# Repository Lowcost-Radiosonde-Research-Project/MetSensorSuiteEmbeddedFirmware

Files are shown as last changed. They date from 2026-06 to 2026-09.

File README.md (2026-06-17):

# Met Pico Sensor Suite - Firmware Skeleton






Status as of latest revision. Every module now has a real
implementation - BMI330's carries a significant caveat (see below and
its module docstring) since its register map is unverified.

## File layout

| File | Status | Notes |
|---|---|---|
| `config.py` | Real | All pins/addresses/constants in one place. Several `TODO`s remain. |
| `packet.py` | Real | Fixed-width binary record format (`PACKET_FORMAT = "<I15fBBBB"`, 68 bytes). |
| `bme280.py` | Real | Full Bosch compensation formulas, forced-mode reads. I2C bus 1. |
| `rtd_ads1115.py`  | Real | Ratiometric RTD read + Callendar-Van Dusen (T >= 0 C only). I2C bus 1. |
| `ms5611.py` | Real | PROM calibration + 1st/2nd-order temp/pressure compensation. I2C bus 2. |
| `bmi330.py` | **Unverified** | Register map guessed from the related BMI323; may not function as intended - see caveat below. I2C bus 2. |
| `gps_neo_m9n.py`  | Real | NMEA GGA parsing: lat/lon/alt/num_sats/UTC time. |
| `sd_logger.py` | Real | Mounts SD, appends `packet.pack_record()` output, periodic flush. |
| `imet_packet.py`  | Real | Builds the 38-byte iMet-1-RSB GPS+PTU-enhanced downlink frame + CRC-16. |
| `link_uart.py` | Real | Frames and sends one 38-byte iMet frame per cycle to the RF Pico over UART. |
| `main.py` | Real | Two I2C buses, SD log + iMet frame to RF Pico link, per-sensor fault isolation. |

Every sensor module exposes `init_<name>(i2c, addr)` returning an
object with a `read()` method, and `main.py` wraps each init in
`try/except (OSError, ValueError)` and each read in `try/except
OSError` (the only error read() can raise) so one bad/missing sensor
doesn't take down the loop or the log - it just logs NAN for that field
and a `[WARN]` line to the console.

## Bus layout

- **I2C bus 1** (`I2C1*`): ADS1115 (RTD) + BME280
- **I2C bus 2** (`I2C2*`): MS5611 + BMI330
- **UART** (`GPS_UART_*`): NEO-M9N GPS
- **UART** (`LINK_UART_*`): outbound link to the RF Pico, one framed
  38-byte iMet-1-RSB frame per cycle (see `imet_packet.py` /
  `link_uart.py`)
- **SPI** (`SD_*`): SD card

All pin numbers above are placeholders pending the Tuesday wiring
session - see the `TODO`s in `config.py`.

## BMI330 caveat - documentation lacking, driver may not work as intended

`bmi330.py` is written against the BMI323's register map (a related
Bosch part) because verified BMI330-specific register documentation
wasn't available when this was written. The register addresses,
ACC_CONF/GYR_CONF bitfield values, and full-scale range assumptions are
all unverified guesses. **The driver may run without raising any error
and still return meaningless numbers.**

On Tuesday, `init_bmi330()` will print whatever it reads from the
assumed CHIP_ID register (0x00) as a diagnostic - note that value down.
If accel/gyro readings look like noise, sit constant, or are far
outside physical range (accelerometer magnitude should be close to 1g
at rest), the register map guess is wrong and `bmi330.py` needs
revisiting against real BMI330 documentation (Bosch's BMI3 Sensor API
repo is the best starting point once it covers BMI330). This isn't
blocking for Wednesday - BMI330 isn't part of that test.

## Field naming convention

`packet.FIELD_NAMES` prefixes every field with the sensor that owns it
(`bme280_*`, `ms5611_*`, `rtd_*`, `bmi330_*`, `gps_*`). BMI330 fields
are in milli-g / milli-deg/s (`_mg` / `_mdps`) rather than g / deg-per-s
- worth keeping in mind when the real BMI330 driver is written, since
the conversion from raw counts will need to land in those units.

The GPS record has `gps_num_sats` plus `gps_hour`/`gps_minute`/
`gps_second` (UTC time of fix), but no fix-type field - `gps.read()`
returns a 7-tuple `(lat, lon, alt, num_sats, hour, minute, second)`.
Position/altitude are NAN and the satellite/time fields are
`NO_DATA_U8` until a checksum-valid GGA sentence with a non-zero fix
quality has been parsed. If you want fix-quality (e.g. for
SondeHub-style reporting) added too, that's a small change to
`packet.py` (one more `B` field) and `gps_neo_m9n.py`'s `_parse_gga()`.

## iMet-1-RSB downlink frame

Each cycle, after the SD record is written, `main.py` builds a
separate 38-byte frame via `imet_packet.pack_frame()` - a GPS Data
Packet (`PKT_ID=0x02`, 18 bytes) immediately followed by a PTU
(enhanced) Data Packet (`PKT_ID=0x04`, 20 bytes), each with its own
CRC-16, matching InterMet's "Appendix A - Binary Radiosonde Packet
Definition" as decoded by `imet1rsb`. This frame - not the `packet.py`
record - is what gets sent over `link_uart` to the RF Pico for AFSK
modulation; `packet.py` stays SD-only.

Current sensor -> iMet field mapping (set in `main.py`, easy to
change - it's just which `record[...]` value is passed to which
`imet_packet` keyword argument):

| iMet field | Source | Notes |
|---|---|---|
| GPS lat/lon/alt/num_sats/hour/min/sec | `gps_*` record fields | real NMEA GGA parsing; NAN/NO_DATA until a fix is acquired |
| P (pressure) | `ms5611_pressure_hpa` | **TODO**: confirm vs. BME280 as the primary pressure source |
| T (primary temp) | `bme280_temp_c` | |
| U (humidity) | `bme280_humidity_pct` | |
| Vbat | hardcoded NAN | **TODO**: no battery-voltage sensing exists yet (new ADC channel) |
| Tint (internal temp) | `bme280_temp_c` | **TODO**: currently duplicates T - confirm intent |
| Tpr (probe temp) | `rtd_temp_c` | |
| Tu (aux temp) | hardcoded NAN | **TODO**: no mapping defined - InterMet's intended use of this field is unclear |

All of the NAN/sentinel placeholders above pack safely (verified in
`imet_packet.py`'s `_scaled_*`/`_encode_altitude` helpers - they map
NAN to the field's "no data" value rather than raising), so the frame
is well-formed even with everything still stubbed.

## Before Tuesday (no hardware needed)

- [ ] Get a copy of `sdcard.py` onto the board. Easiest path in
      Thonny/REPL: `import mip; mip.install("sdcard")`. This is the
      standard MicroPython SD-over-SPI block driver - `sd_logger.py`
      imports it as `sdcard`.
- [ ] Skim `config.py` for the `TODO` items - nothing blocks you from
      reading the code now, but these are the values you'll set Tuesday.

## Tuesday, once hardware is in hand

- [ ] Update `config.py` pin numbers for both I2C buses, SPI (SD), GPS
      UART, the RF Pico link UART, and `REGULATOR_EN_PIN` (LM2596 3.3V
      rail enable) to match actual wiring.
- [ ] Confirm `RTD_MUX` / `REF_MUX` (which ADS1115 differential pair is
      the RTD vs. the reference resistor) and `ADS1115_GAIN` (PGA
      setting), based on the RTD interface board.
- [ ] Confirm `MS5611_I2C_ADDR` and `BMI330_I2C_ADDR` once those boards
      are wired. MS5611 and GPS now have real drivers, so a wrong
      address will surface as `[WARN] ... init failed` from
      `_safe_init` rather than silently logging NaN.
- [ ] For BMI330: note the `[INFO] BMI330 CHIP_ID register read as
      0x..` line at startup and sanity-check accel/gyro readings
      against the caveat above - this driver's register map is a
      guess.
- [ ] Run `main.py`. With only BME280 + RTD wired, expect `[WARN]`
      lines at startup for MS5611/BMI330/GPS init or SD mount (if not
      present) - that's expected, the loop should keep running and
      print live T/P/RH/RTD values once per second.

## Wednesday (storm chase)

The console line each cycle:

```
t=   12345ms  T= 23.45C  P=1006.32hPa  RH= 45.2%  RTD= 23.10C
```

gives a live sanity check that BME280 and RTD agree roughly with each
other and with ambient conditions. The SD card (if mounted) accumulates
`PACKET_SIZE`-byte (68-byte) binary records in `/sd/metlog.bin` - decode
with `packet.unpack_record()` in a small post-processing script, reading
`PACKET_SIZE` bytes at a time.

## Known gaps / next steps

- RTD conversion only handles T >= 0 C (Callendar-Van Dusen quadratic
  inversion). The sub-zero cubic-term inversion needs to be added before
  the actual flight.
- BMI330 is unverified - see the dedicated caveat section above and
  `bmi330.py`'s module docstring before trusting any IMU data.
- `link_uart.py` now sends a 38-byte iMet frame instead of the
  65-byte `packet.py` record - see "iMet-1-RSB downlink frame" above
  for the sensor mapping and its open TODOs (Vbat sensing, GPS UTC
  time, P/Tint/Tu assignment).
- `imet_packet.py` matches the field layout and CRC algorithm from
  `imet1rsb.c`'s source, but hasn't been cross-checked byte-for-byte
  against a compiled run of that decoder yet. Worth doing once there's
  a spare moment - compile `imet1rsb.c`, feed it a known frame, and
  confirm its `crc16()` agrees with `imet_packet.crc16()`.
- The RF Pico's receive-side parser for `link_uart`'s frame format
  (sync bytes + length + checksum) doesn't exist yet - that's firmware
  for the other board, out of scope here, but the frame format is
  documented at the top of `link_uart.py` so it can be matched.
- `main.py` currently runs everything on a single core via a simple
  fixed-interval loop. If SD writes, link UART sends, or sensor reads
  start causing timing jitter once everything is real, revisit
  splitting acquisition and logging across the two cores with
  `_thread`.

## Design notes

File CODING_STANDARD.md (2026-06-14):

# Lowcost Radiosonde Research Project - Coding Standard

**Revision:** 1.0
**Applies to:** All firmware (C/Pico SDK , MicroPython) and ground-station tooling.

## Table of Contents

1. [General Principles](#1-general-principles)
2. [Repository Structure](#2-repository-structure)
3. [C - Pico SDK Firmware](#3-c--pico-sdk-firmware)
    - 3.1 [Naming Conventions](#31-naming-conventions)
    - 3.2 [Formatting & Braces](#32-formatting-braces)
    - 3.3 [Comments & Documentation](#33-comments--documentation)
    - 3.4 [Header Files](#34-header-files)
    - 3.5 [Error Handling](#35-error-handling)
    - 3.6 [Types & Fixed Width Integers](#36-types--fixed-width-integers)
    - 3.7 [Memory & Pointer](#37-memory--pointers)
    - 3.8 [Interrupt & DMA Safety](#38-interrupt--dma-safety)
4. [MicroPython](#4-micropython)
    - 4.1 [Naming Conventions](#41-naming-conventions)
    - 4.2 [Formatting](#42-formatting)
    - 4.3 [Comments & Docstrings](#43-comments--docustrings)
    - 4.4 [Error Handling](#44-error-handling)
5. [Version Control Practices](#5-version-control-practices)
6. [Build System](#6-build-system)

---

## 1. General Principles
- **Clarity over cleverness** You are not the only one reading your code. Please favor explicit, readable constructs even when a terse alternative exists.

- **One concern per module** Each file `.c`/`.h` or `.py` file should address a single problem. It should contain a single logical subsystem e.g. : GPS parsing, sensor acquisition, telemetry framing, etc..
- **Fail loudly in development not in flight** Use assertions and diagnostic output debug builds; ensure flight builds degrade safely without halting.
- **Document the *why* and not the *what*** The code itself shows what is happening; comments should explain non-obvious design decisions and hardware-specific constraints.

---

## 2. Repository Structure

coming soon / not needed for this file

---

## 3. C - Pico SDK Firmware

### 3.1 Naming Conventions
| Construct | Convention | Example |
|---|---|---|
|Functions| `module_verb_noun()` snake_case |`gps_parse_frame()` |
|Variables (local) | snake_case | `byte_count`|
|Variables (global) | `g_` prefix + snake_case | `g_fix_valid` |
|Constraints / `#define` | SCREAMING_SNAKE_CASE | `MAX_PACKET_LENGTH` |
| Macros | SCREAMING_SNAKE_CASE | `SWAP_BYTES(x)` |
| Typedefs (structs) | PascalCase + `_t` suffix | `GpsFrame_t` |
| Enums | PascalCase + `_t` suffix , members prefixed | `TxState_t`, `TX_IDLE` |
| File names | snake_case | `telemetry_encoder.c` |

### 3.2 Formatting & Braces

**Allman style is mandatory** for all control flow constructs. Opening braces should go on their own line.

```c
/* Correct - Allman style */
if (fix_valid)
{
    gps_parse_frame(&frame);
}
else
{
    log_warn("No GPS fix");
}

/* Incorrect */
if (fix_valid){
    gps_parse_frame(&frame);
}
```
Additional rules:

- **Indent with 4 spaces**
- **Line length:** Keep lines at or under 100 chars
- **One statement per line** Never write `if(x) do_thing();` on a single line.
- **Always brace single-statement bodies.** Omitting braces for one-liner `if`/`for` bodies is not permitted.
- **Blank lines:** Use a single blank line to separate logical sections within a function; two blank lines between top-level definitions in a file.
- **Pointer declarations:** Right attach '*' ie attach to the variable name, not type.

```c
uint8_t *buf;  /*correct*/
uint8_t* buf; /*incorrect */
```
### 3.3 Comments & Documentation

Use Doxygen-style block comments on all public functions and type definitions in headers:

```c
/**
 * @brief Parse a raw NMEA sentence into a GpsFrame_t.
 *
 * @param sentence Null-terminated NMEA string (e.g. "$GPGGA,....").
 * @param out      Pointer to a caller-allocated GpsFrame_t to populate.
 * @return true on successful parse, false if the sentence is malformed or the checksum fails
 */
 bool gps_parse_sentence(const char *sentence, GpsFrame_t *out);
```
Inline comments use '/* */' and are placed **above** the line they describe, not at the end of the line, unless the comment is very short:
```c
/* Correct */
/* Shift left by 4 to align the SI4063 register format. */
reg_val = raw_freq << 4;
/* Acceptable for short notes. */
uint32_t timeout_ms = 500; /* POR stabilisation time per datasheet */
```
Do not leave commented-out code in committed files. Use version control to recover old implementations.

### 3.4 Header Files

- Use `#pragma once` at the top of every header.
- Headers expose **Only what the consumers need**. Keep internal helpers in the `.c` file or in a separate `_internal.h` that is not installed.
- Always include all headers that your header directly depends on - do not rely on transitive inclusion.
- Group includes in the following order, separated by a blank line:
    1. Standard C headers (`<stdint.h>`, `<stdbool.h>`, etc.)
    2. Pico SDK headers (`"pico/stdlib.h"`, `"hardware/uart.h"`, etc.)
    3. Project headers (`"gps.h"`, `"telemetry.h"`, etc.)

```c
#pragma once

#include <stdint.h>
#include <stdbool.h>

#include "pico/stdlib.h"
#include "hardware/spi.h"

#include "telemetry.h"
```

### 3.5 Error Handling

- Functions that can fail **must** return a status. Prefer `bool` for simple pass/fail, or a project-defined `SondeStatus_t` enum for multi-error subsystem.
-Never silently discard a return value from a function that can fail. If the result is intentionally unused, cast to `(void)`;
- In debug builds, use `assert()` to catch programming errors. In flight builds, assert should compile out (`NDEBUG`).
- Do not use `while(1)` panic loops in flight code - always attempt graceful recovery or safe-state entry.

### 3.6 Types & Fixed-Width Integers

- Prefer fixed-width types from `<stdint.h>` for all hardware-interfacing protocol code: `uint8_t`, `uint16_t`, `uint32_t`, etc..
- Use `size_t` for buffer lengths and loop indices over arrays.
- Use `bool` (from `<stdbool.h>`) for boolean states. Never use `int` as a boolean.
- Avoid `float` in ISR context. Use fixed-point (`int32_t` with a documented scale factor) or defer float math to the main loop.

### 3.7 Memory & Pointers

- No dynamic memory allocation (`malloc`/`free`) in flight firmware. All buffers are statically allocated.
- Clearly document buffer ownership: who allocates, who frees (if ever), and who may write.
- Mark pointers to read-only data as `const`.
- Mark output-only pointer parameters clearly in the Doxygen `@param` docs.

### 3.8 Interrupt & DMA Safety

- Variables shared between ISR and main-loop context **must** be declared `volatile`.
- Accesses to multi-byte shared variables must be protected (disable IRQ + restore, or use the Pico SDK's `__dmb()` / critical section APIs).
- Keep ISR bodies minimal - set a flag or write a ring buffer; do all heavy processing in the main loop.
- DMA buffer pointers must be 4-byte aligned. Use `__attribute__((aligned(4)))`.

---

## 4. MicroPython

### 4.1 Naming Conventions

| Construct | Convention | Example |
|---|---|---|
| Functions | snake_case | `decode_frame` |
|Variables | snake_case | `packet_count`|
|Constants | SCREAMING_SNAKE_CASE | `BAUD_RATE` |
| Classes | PascalCase | `SondeDecoder` |
| Private members | leading underscore | `_checksum_` |
| Modules/files | snake_case | `telemetry_decoder.py` |

### 4.2 Formatting

- Follow **PEP 8** as the baseline style guide.
- **Indent with 4 spaces**
- **Line length:** 100 character maximum (to stay consistent with the C standard above).
- Two blank lines between top-level function and class definitions; one blank line between methods within a class.
- Imports are grouped in PEP 8 order (stdlib -> third-party -> local), each grouped separated by a blank line.

```python
import struct
import sys

import serial

from sonde.telemetry import SondeDecoder
```

### 4.3 Comments and Docstrings

All public functions, classes, and methods get a docstring. Use Google-style docstrings:

```python
def decode_frame(raw: bytes) -> dict:
    """Decode a raw telemetry frame into a dictionary of sensor values.

    Args:
        raw: Raw byte payload from the radio receiver, including the
             2-byte sync word and trailing CRC.
    
    Returns:
        A dict with keys 'lat', 'lon', 'alt_m', 'temp_c', 'rh_pct',
        'pressure_hpa'. Missing or invalid fields are None.

    Raises:
        ValueError: If the sync word is absent or the CRC fails.
    """
```

Inline comment us `#` with a single space, placed above the relevant line:

```python
# Convert raw ADC count to temperature using datasheet equation
temp_c = (raw_adc * 0.0625) - 40.0
```

### 4.4 Error Handling

- Use specific exception types, never bare `except:`.
- Log errors with enough context to reconstruct what went wrong (packet binary dump, timestamp, etc.).
- Ground-station tools should never crash silently -  at a minimum, print a human readable error and continue or exit cleanly

```python
try:
    frame = decode_frame(raw_bytes)
except ValueError as e:
    print(f"[WARN] Bad frame at t = {timestamp}: {e} | raw = {raw_bytes.binary()}")
    continue
```

---

## 5. Version Control Practice (Git)

- **Branch naming:** `feature/<short-description>`, `fix/<short-description>`, `chore/<short-description>`.
- **Commit messages** Use the imperative mood and keep the subject line under 72 characters.
    - Good: `Added GPS checksum validation to parser`
    - Bad: `fixed stuff` / `WIP`
- Every commit on `main` must build cleanly with zero warning s at the project's standard warning level (`-Wall -Wextra` for C).
- Do not commit generated build artifacts, `.uf2` binaries, or IDE-specific files. Use `.gitignore`.

---

## 6. Build Systems

- The firmware uses **CMake** via the Pico SDK's standard project structure.
- Enable warnings-as-errors in CI: ass `--Werror` to `CMAKE_C_FLAGS` in the CI build configuration (not in the development default, to avoid friction during active development).
- The recommended compiler flag set for development builds:

```cmake
target_compile_options(sonde_firmware PRIVATE
    -Wall
    -Wextra
    -Wshadow
    -Wdouble-promotion
    -Wformat=2
    -fno-common
)
```

- Python tooling dependencies are pinned in `tools/requirements.txt` with exact versions.

---
*This document is a living standard. Propose changes via pull request with a brief rational in the PR description.*

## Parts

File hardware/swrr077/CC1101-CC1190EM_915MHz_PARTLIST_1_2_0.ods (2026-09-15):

CC1101-CC1190EM 915 MHz 1.2.0
Ref. | Part name | Pcs/unit | Description | Manufacturer | Part number | Supplier | Ordering code | Alt. Manufacturer | Alt. Part number | Alt. Supplier | Alt. Ordering code | Comments
U1 | CC1101 | 1 | Single-chip transceiver | TI | CC1101 | TI | U1 | CC1101 | 1 | Single-chip transceiver | TI | CC1101 | TI | CC1101
U2 | CC1190 | 1 | LNA and PA 26 dBm | TI | CC1190 | TI | CC1190
C28 | C_0402 | 1 | Capacitor, general, 0402; Do not mount
C125 | C_0P8_0402_NP0_B_50 | 1 | Capacitor, 0.8p, 0402, NP0, +/-0.1pF, 50V | Murata | GRM1555C1HR80BZ01D
C41;C51;C91;C111;C141;C151;C181 | C_100N_0402_X5R_K_10 | 7 | Capacitor, 100n, 0402, X5R, 10%, 10V | Murata | GRM155R71A104KA01D
C124 | C_100P_0402_NP0_J_50 | 1 | Capacitor, 100p, 0402, NP0, 5% 50V | Murata | GRM1555C1H101JZ01D
C2 | C_10U_0603_X5R_M_4 | 1 | Capacitor, 10u, 0603, X5R, 20%, 4V | Murata | GRM188R60G106ME47D
C22;C52;C81 | C_12P_0402_NP0_J_50 | 3 | Capacitor, 12p, 0402, NP0, 5%, 50V | Murata | GRM1555C1H120JZ01D
C101;C132 | C_15P_0402_NP0_J_50 | 2 | Capacitor, 15p, 0402, NP0, 5%, 50V | Murata | GRM1555C1H150JZ01D
C27 | C_1N_0402_NP0_J_50 | 1 | Capacitor, 1n, 0402, NP0, 5%, 50V | Murata | GRM1555C1H102JA01D
C121 | C_1P0_0402_NP0_C_50 | 1 | Capacitor, 1p, 0402, NP0, +/-0.25pF 50V | Murata | GRM1555C1H1R0CZ01D
C122;C131 | C_1P5_0402_NP0_C_50 | 2 | Capacitor, 1p5, 0402, NP0, +-0.25pF, 50V | Murata | GRM1555C1H1R5CZ01D
C1;C30 | C_1U_0402_X5R_K_6P3 | 2 | Capacitor, 1u, 0402, X5R, 10%, 6.3V | Murata | GRM155R60J105KE19D
C3 | C_220P_0402_NP0_J_50 | 1 | Capacitor, 220p, 0402, NP0, 5%, 50V | Murata | GRM1555C1H221JA01D
C161 | C_27P_0402_NP0_J_50 | 1 | Capacitor, 27p, 0402, NP0, 5%, 50V | Murata | GRM1555C1H270JZ01D
C24 | C_3P3_0402_NP0_C_50 | 1 | Capacitor, 3p3, 0402, NP0, +-0.25pF, 50V | Murata | GRM1555C1H3R3CZ01D
C21;C26;C123 | C_47P_0402_NP0_J_50 | 3 | Capacitor, 47p, 0402, NP0, 5%, 50V | Murata | GRM1555C1H470JZ01D
C25 | C_7P5_0402_NP0_C_50 | 1 | Capacitor, 7p5, 0402, NP0, +/-0.25pF 50V | Murata | GRM1555C1H7R5CZ01D
U3 | EPCOS_B3588 | 1 | SAW filter, 915 MHz | EPCOS | B3588 | Arrow | B39921B3588U410
L25 | L_10N_0402_G_LQW | 1 | Inductor, 10n, 0402, ±2%, wire-wound type | Murata | LQW15AN10NG00D | Mouser | 81-LQW15AN10NG00D
L2 | L_11N_0402_J_LQW | 1 | Inductor, 11n, 0402, ±5%, wire-wound type | Murata | LQW15AN11NJ00
L121;L131 | L_12N_0402_J_LQW | 2 | Inductor, 12n, 0402, ±5%, wire-wound type | Murata | LQW15AN12NJ00D
L122;L132 | L_18N_0402_J_LQW | 2 | Inductor, 18n, 0402, ±5%, wire-wound type | Murata | LQW15AN18NJ00D
L130 | L_1N5_0402_S | 1 | Inductor, 1n5, 0402, Monolithic type, +/-0.3 nH | Murata | LQG15HS1N5S02D |  |  | Coilcraft
L21 | L_22N_0603_J_LQW | 1 | Inductor, 22n, 0603, ±5%, wire-wound type | Murata | LQW18AN22NJ10
L23 | L_2N9_0402_B_LQW | 1 | Inductor, 2n9, 0402, wire-wound type, ±0.1nH | Murata | LQW15AN2N9B00D
L22 | L_7N5_0402_G_LQW | 1 | Inductor, 7n5, 0402, ±2%, wire-wound type | Murata | LQW15AN7N5G00 | ACTE
L24 | L_9N1_0402_G_LQW | 1 | Inductor, 9n1, 0402, ±2%, wire-wound type | Murata | LQW15AN9N1G00D
L1 | L_BEAD_102_0402 | 1 | EMI filter bead, 0402 1k ohms Tape GHz Band Gen Use | Murata | BLM15HG102SN1D | ACTE
P4 | PINROW_SMD_2X7_2.54MM_PEG | 1 | 2x7 pinrow, 2.54mm pitch, SMD type with locating peg | GradConn | BB02-HP141-KB3-060A00 | Freber
R3-5 | R_10K_0402_F | 3 | Resistor, 10k ohms, 0402, ±1% | Koa | RK73H1ETTP1002F | ELFA | 60-485-32
R161 | R_10_0402_G | 1 | Resistor, 10 ohms, 0402, 2% | Koa | RK73H1ETTP10R0F (±1%) | ELFA | 60-470-96
R141 | R_3K3_0402_F | 1 | Resistor, 3k3 ohms, 0402, ±1% | Koa | RK73H1ETTP3301F | ELFA | 60-482-92
R151 | R_47_0402_G | 1 | Resistor, 47 ohms, 0402, 2% | Koa | RK73H1ETTP47R0F (±1%) | ELFA | 60-474-19
R171 | R_56K_0402_F | 1 | Resistor, 56k ohms, 0402, ±1% | Koa | RK73H1ETTP5602F | ELFA | 60-488-96
P3 | SMA_SMD | 1 | SMA connector, straight SMD-mount | Hus-Tsan Group Taiwan | SMA-10V21-TGG | EC Partner A/S | SMA-10V21-TGG
P1-2 | SMD_SOCKET_2x10 | 2 | SMD pinrow socket, .050 spacing, 2x10 | Samtec | SFM-110-02-SM-D-A-K-TR | Abacus |  |  |  | AFU, Arrow |  | Yes
P5 | Shield BMIS-202 | 1 | Surface Mount Shield Two-Piece. Cover ordered separately | Laird | BMI-S-202-F | ELFA | 50-011-28
P5 cover | Shield BMIS-202 cover | 1 | Cover for SHIELD BMIS-202 | Laird | BMI-S-202-C | ELFA | 50-011-36
X1 | X_26.000/20/40/40/10 | 1 | Crystal, 26.000000MHz, 10.0pF, 50 ohms max, 20/40 ppm, -40C to +85C | NDK | NX3225GA, EXS00A-CG01972 | NDK | NX3225GA, EXS00A-CG01972
Total number of components |  | 58

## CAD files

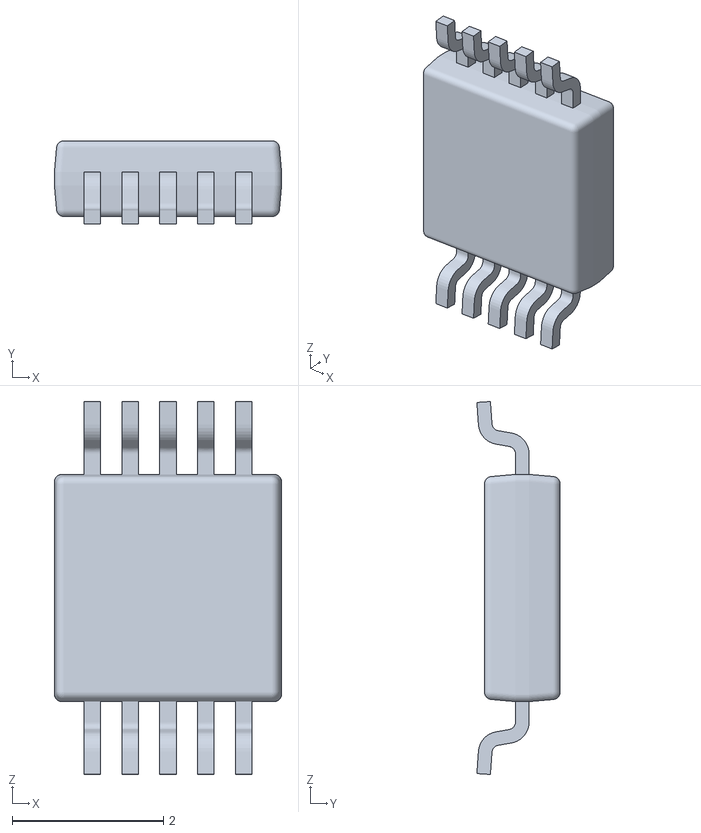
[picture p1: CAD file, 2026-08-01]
hardware/Parts/ADS1115LIDGSR/DGS0010A.stl
3.00 x 1.10 x 4.93

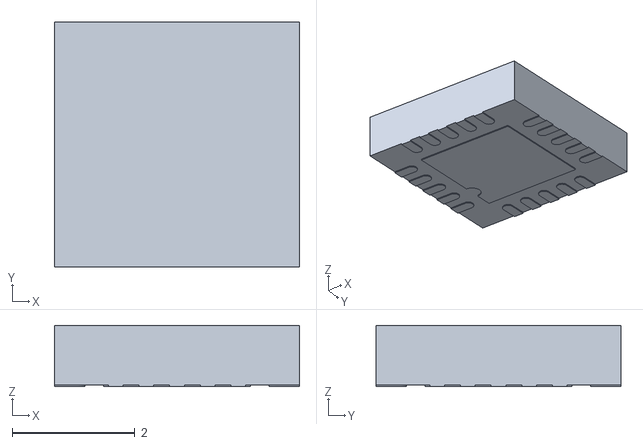
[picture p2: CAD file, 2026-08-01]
hardware/Parts/CC1101RGPR/RGP0020H.stl
4.00 x 4.00 x 1.00

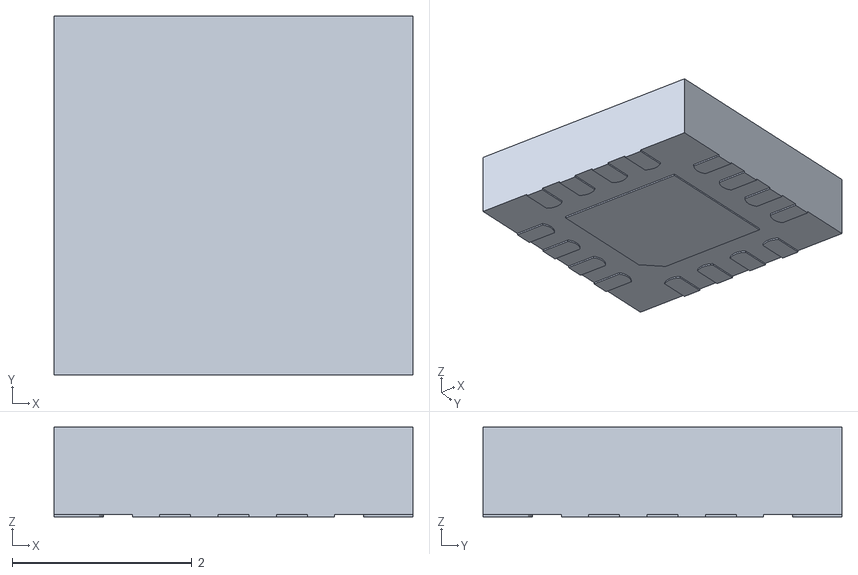
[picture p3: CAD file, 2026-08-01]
hardware/Parts/CC1190RGVT/RGV0016A.stl
4.00 x 4.00 x 1.00

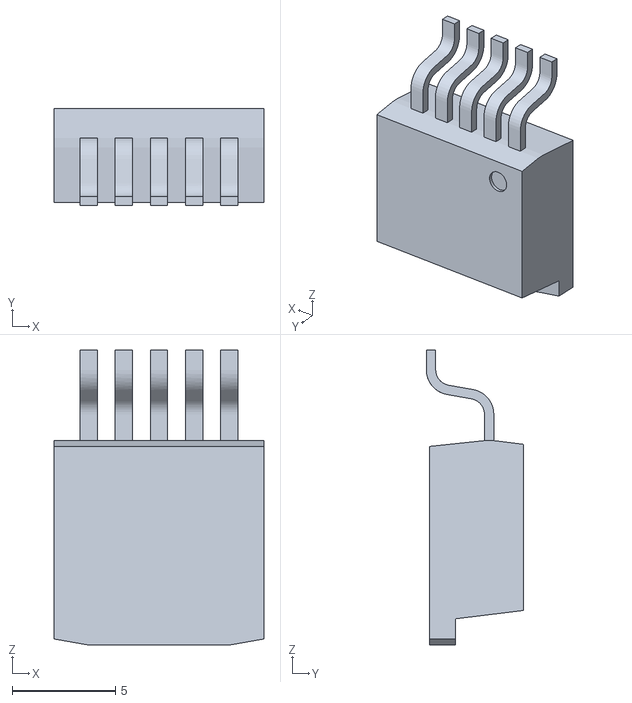
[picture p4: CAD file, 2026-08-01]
hardware/Parts/LM2596SX_3_3_NOPB/KTT0005B.stl
10.2 x 4.72 x 14.3

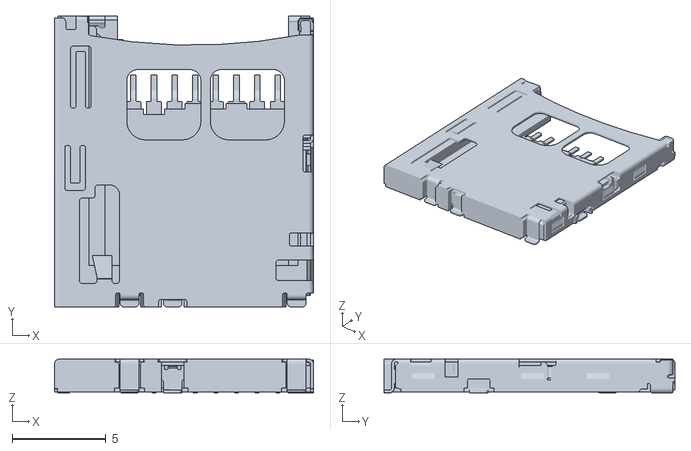
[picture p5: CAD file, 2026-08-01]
hardware/Parts/5025700893/5025700893.stl
13.8 x 15.5 x 1.80

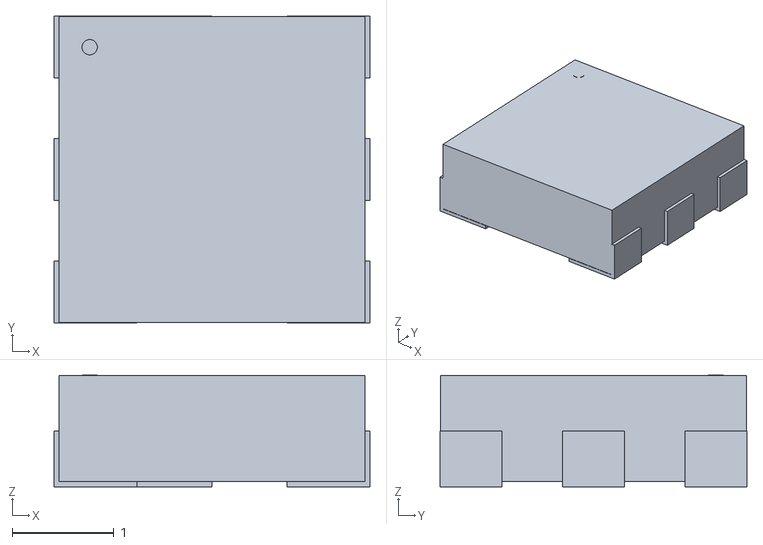
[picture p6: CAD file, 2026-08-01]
hardware/Parts/B39921B3588U410/B39162B3522U410_TDK.stl
3.10 x 3.01 x 1.10

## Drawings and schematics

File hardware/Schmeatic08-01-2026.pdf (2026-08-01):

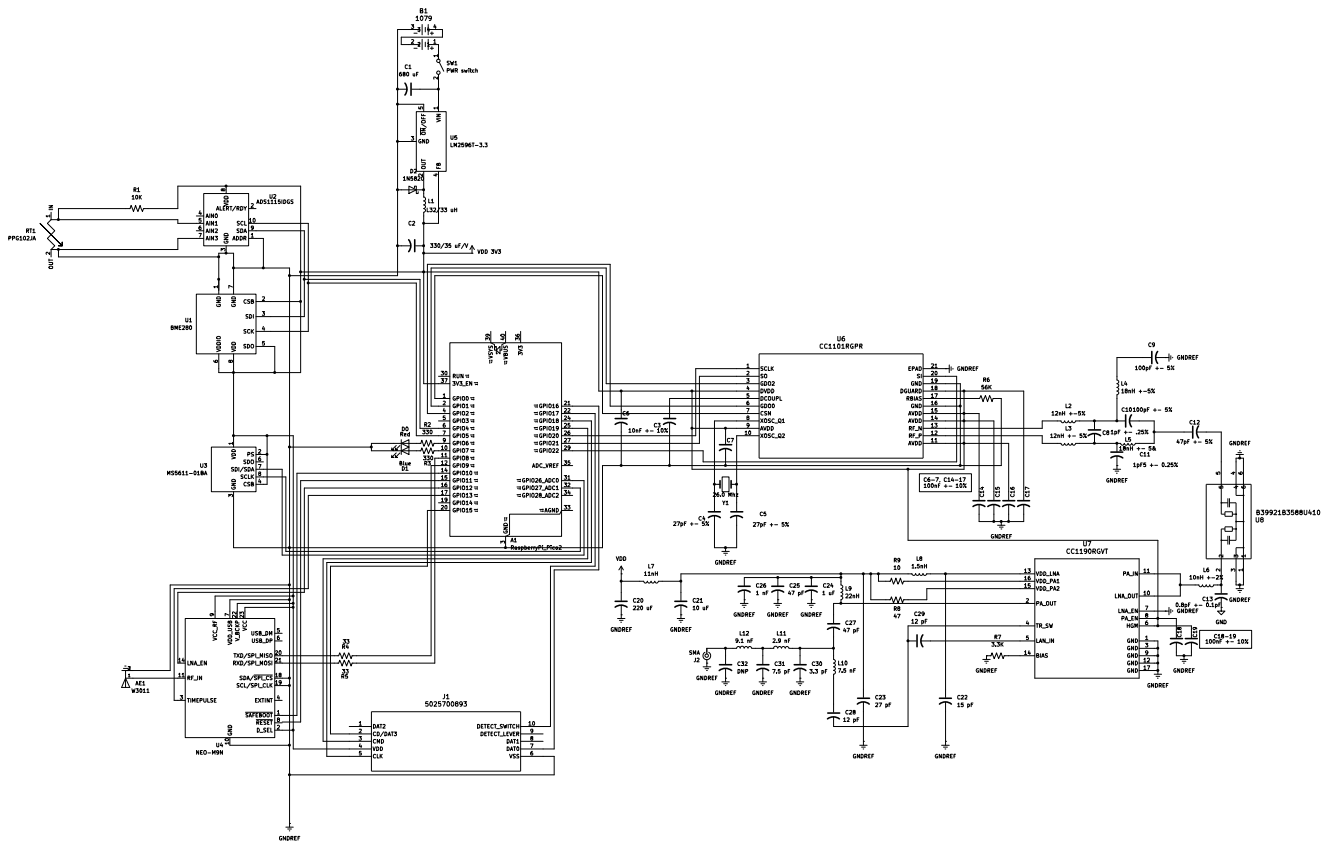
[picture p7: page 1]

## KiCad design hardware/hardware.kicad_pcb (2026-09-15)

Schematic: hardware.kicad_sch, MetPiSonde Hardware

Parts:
A1: RaspberryPi_Pico2; RaspberryPi_Pico_Common_SMD; Digikey Part Number 2648-SC1631CT-ND
C1, C30: 1uF; C_0603_1608Metric; Digikey Part Number 490-GRM188R61C105KA12JCT-ND
C2: 10uF; C_0603_1608Metric; Digikey Part Number 490-12538-1-ND
C3: 220pF; C_0603_1608Metric; Digikey Part Number 720-VJ0603D221JXJQJHTCT-ND
C21, C26, C123: 47pF; C_0603_1608Metric; Digikey Part Number 399-17536-1-ND
C22, C52, C81: 12pF; C_0603_1608Metric; Digikey Part Number 399-CBR06C120J5GACCT-ND
C24: 3.3pF; C_0805_2012Metric; Digikey Part Number 490-GQM2195C2E3R3CB12DCT-ND - Cut Tape 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
C25: 7.5pF; C_1206_3216Metric; Digikey Part Number 399-16247-1-ND - Cut Tape (CT)
C27: 1nF; C_0805_2012Metric; Digikey Part Number 720-VJ0805D102JXJQJHTCT-ND
C28: DNP; C_1206_3216Metric; not fitted
C41, C51, C91, C111, C141, C151, C181: 100nF; C_0805_2012Metric; Digikey Part Number 478-KGM21NR71H104KTCT-ND
C101, C132: 15pF; C_0603_1608Metric; Digikey Part Number 399-CBR06C150J5GACAUTOCT-ND
C121: 1.9pF; C_0603_1608Metric; Digikey Part Number 399-16151-1-ND - Cut Tape (CT
C122, C131: 1.5pF; C_0805_2012Metric; Digikey Part Number 490-5282-1-ND - Cut Tape (CT)
C124: 100pF; C_0805_2012Metric; Digikey Part Number 478-KGQ21HCG2D101JTCT-ND
C125: 0.8pF; C_0805_2012Metric; Digikey Part Number 490-GQM2195G2ER80BB12DCT-ND - Cut Tape 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
C161: 27pF; C_0805_2012Metric; Digikey Part Number 478-KGQ21HCG2D270JTCT-ND
D1: Red LED; LED_D5.0mm; Digikey Part Number 732-5016-ND
D2: Blue LED; LED_D5.0mm; Digikey Part Number 732-5015-ND
FB1: FerriteBead; L_1206_3216Metric; Digikey Part Number 240-2397-1-ND
J1: SMA; SMA_Molex_73251-1153_EdgeMount_Horizontal
J2: Test Header; PinHeader_2x12_P2.54mm_Vertical
L2: 11nH; L_0603_1608Metric; Digikey Part Number 490-LQW18AS11NG00DCT-ND
L21: 22nH; L_0603_1608Metric; Digikey Part Number 490-LQW18AS22NG00DCT-ND
L22: 7.5nH; L_0603_1608Metric; Digikey Part Number 490-LQW18AS7N5G00DCT-ND
L23: 2.9nH; L_0402_1005Metric; Digikey Part Number 490-LQG15WZ2N9B02DCT-ND
L24: 9.1nH; L_0402_1005Metric; Digikey Part Number 490-LQG15HS9N1G02DCT-ND
L25: 10nH; L_0603_1608Metric; Digikey Part Number 490-LQW18AS10NG00DCT-ND
L121, L131: 12nH; L_0603_1608Metric; Digikey Part Number 490-15799-1-ND
L122, L132: 18nH; L_0603_1608Metric; Digikey Part Number 490-15805-1-ND
L130: 1.5nH; L_1206_3216Metric; Digikey Part Number 490-1100-1-ND
P5: BMI-S-205-C; Laird_Technologies_BMI-S-203-F_26.21x26.21mm; Digikey Part Number 903-1014-ND
R1, R2: 330; R_0603_1608Metric; Digikey Part Number MCT06030C3300FP500
R3, R4, R5: 10K; R_0603_1608Metric; Digikey Part Number MCT0603-10.0K-CFCT-ND
R141: 3.3k; R_0603_1608Metric; Digikey Part Number MCT0603-3.30K-CFCT-ND
R151: 47; R_0603_1608Metric; Digikey Part Number MCT0603-47.0-CFCT-ND
R161: 10; R_0603_1608Metric; Digikey Part Number MCT0603-10.0-CFCT-ND
R171: 56K; R_0603_1608Metric; Digikey Part Number 749-1667-1-ND
TP1, TP2: TestPoint; PinHeader_1x01_P2.54mm_Vertical; Digikey Part Number JSTXH
U1: CC1101; Texas_RGP0020H_VQFN-20-1EP_4x4mm_P0.5mm_EP2.4x2.4mm_Thermal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; Digikey Part Number 296-35718-1-ND
U2: CC1190; RGV0016A; Digikey Part Number 296-36922-1-ND
U3: B39921B3588U410; B39162B3522U410_TDK-L; Digikey Part Number 495-1674-1-ND
X1: 26.000 MHz; Crystal_SMD_2016-4Pin_2.0x1.6mm; Digikey Part Number 478-CX2016FB26000F0FZZH1CT-ND

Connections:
GND: A1.3 (GND), A1.8 (GND), A1.13 (GND), A1.18 (GND), A1.23 (GND), A1.28 (GND), A1.33 (AGND), A1.38 (GND), C1.2, C2.2, C3.2, C24.2, C25.2, C26.2, C27.2, C28.2, C30.2, C41.2, C51.2, C81.2, C91.2, C101.2, C111.2, C124.2, C125.2, C131.2, C132.2, C141.2, C151.2, C161.2, C181.2, D1.1 (K), D2.1 (K), J1.2 (Ext), J2.13, J2.14, J2.24, P5.1 (Shield_1), R141.1, R171.2, U1.16 (GND), U1.19 (GND), U1.21 (EPAD), U2.1 (GND), U2.3 (GND), U2.9 (GND), U2.12 (GND), U2.17 (GND), U3.1, U3.3, U3.4, U3.6; also elsewhere on the board
GPS_EXT_INT: A1.5 (GPIO3), J2.5; also elsewhere on the board
GPS_RESET_N: A1.4 (GPIO2), J2.4; also elsewhere on the board
GPS_RX: A1.2 (GPIO1), J2.3; also elsewhere on the board
GPS_TX: A1.1 (GPIO0), J2.2; also elsewhere on the board
HGM: A1.27 (GPIO21), J2.17, R3.2
I2C0_SCL: A1.7 (GPIO5), J2.7, J2.16; also elsewhere on the board
I2C0_SDA: A1.6 (GPIO4), J2.6, J2.15; also elsewhere on the board
I2C1_SCL: A1.31 (GPIO26_ADC0); also elsewhere on the board
I2C1_SDA: A1.32 (GPIO27_ADC1); also elsewhere on the board
LED_GPSF: A1.10 (GPIO7), R2.2
LED_PWR: A1.9 (GPIO6), R1.2
LNA_EN: A1.26 (GPIO20), J2.18, R4.2
unnamed: C21.1, C24.1, L22.1, L23.1
unnamed: C22.1, L22.2
unnamed: C25.1, L23.2, L24.1
unnamed: C121.1, C122.1, L121.1, L122.2
unnamed: C121.2, C131.1, L131.1, L132.2
unnamed: C122.2, C123.1, L132.1
unnamed: C123.2, U3.5
unnamed: C124.1, L122.1
unnamed: C125.1, L25.2, U3.2
unnamed: C2.1, C26.1, C27.1, C30.1, C161.1, L2.1, L21.1, L130.1, R151.1, R161.1
unnamed: D1.2 (A), R1.1
unnamed: D2.2 (A), R2.1
unnamed: C28.1, J1.1 (In), L24.2
unnamed: C51.1, U1.5 (DCOUPL)
unnamed: C1.1, C41.1, C91.1, C111.1, C141.1, C151.1, C181.1, FB1.1, U1.4 (DVDD), U1.9 (AVDD), U1.11 (AVDD), U1.14 (AVDD), U1.15 (AVDD), U1.18 (DGUARD)
unnamed: TP1.1 (1_1), U1.6 (GDO0)
unnamed: TP2.1 (1_1), U1.3 (GDO2)
unnamed: R171.1, U1.17 (RBIAS)
unnamed: L131.2, U1.13 (RF_N)
unnamed: L121.2, U1.12 (RF_P)
unnamed: C81.1, U1.8 (XOSC_Q1), X1.1
unnamed: C101.1, U1.10 (XOSC_Q2), X1.2
unnamed: R141.2, U2.14 (BIAS)
unnamed: R3.1, U2.6 (HGM)
unnamed: R4.1, U2.7 (LNA_EN)
unnamed: C52.2, U2.5 (LNA_IN)
unnamed: L25.1, U2.10 (LNA_OUT), U2.11 (PA_IN)
unnamed: R5.1, U2.8 (PA_EN)
unnamed: C21.2, L21.2, U2.2 (PA_OUT)
unnamed: C22.2, C52.1, U2.4 (TR_SW)
unnamed: C132.1, L130.2, U2.13 (VDD_LNA)
unnamed: R161.2, U2.16 (VDD_PA1)
unnamed: R151.2, U2.15 (VDD_PA2)
PA_EN: A1.19 (GPIO14), J2.12, R5.2
SD_CSn: A1.22 (GPIO17), J2.21; also elsewhere on the board
SD_DETECT: A1.20 (GPIO15), J2.23; also elsewhere on the board
SD_RX: A1.21 (GPIO16), J2.22; also elsewhere on the board
SD_SCK: A1.24 (GPIO18), J2.20; also elsewhere on the board
SD_TX: A1.25 (GPIO19), J2.19; also elsewhere on the board
SPI1_CSn: A1.17 (GPIO13), J2.11, U1.7 (CSN)
SPI1_RX: A1.16 (GPIO12), J2.10, U1.2 (SO)
SPI1_SCK: A1.14 (GPIO10), J2.8, U1.1 (SCLK)
SPI1_TX: A1.15 (GPIO11), J2.9, U1.20 (SI)
VDD: A1.39 (VSYS), C3.1, FB1.2, J2.1, L2.2; also elsewhere on the board

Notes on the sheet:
Goes over U2

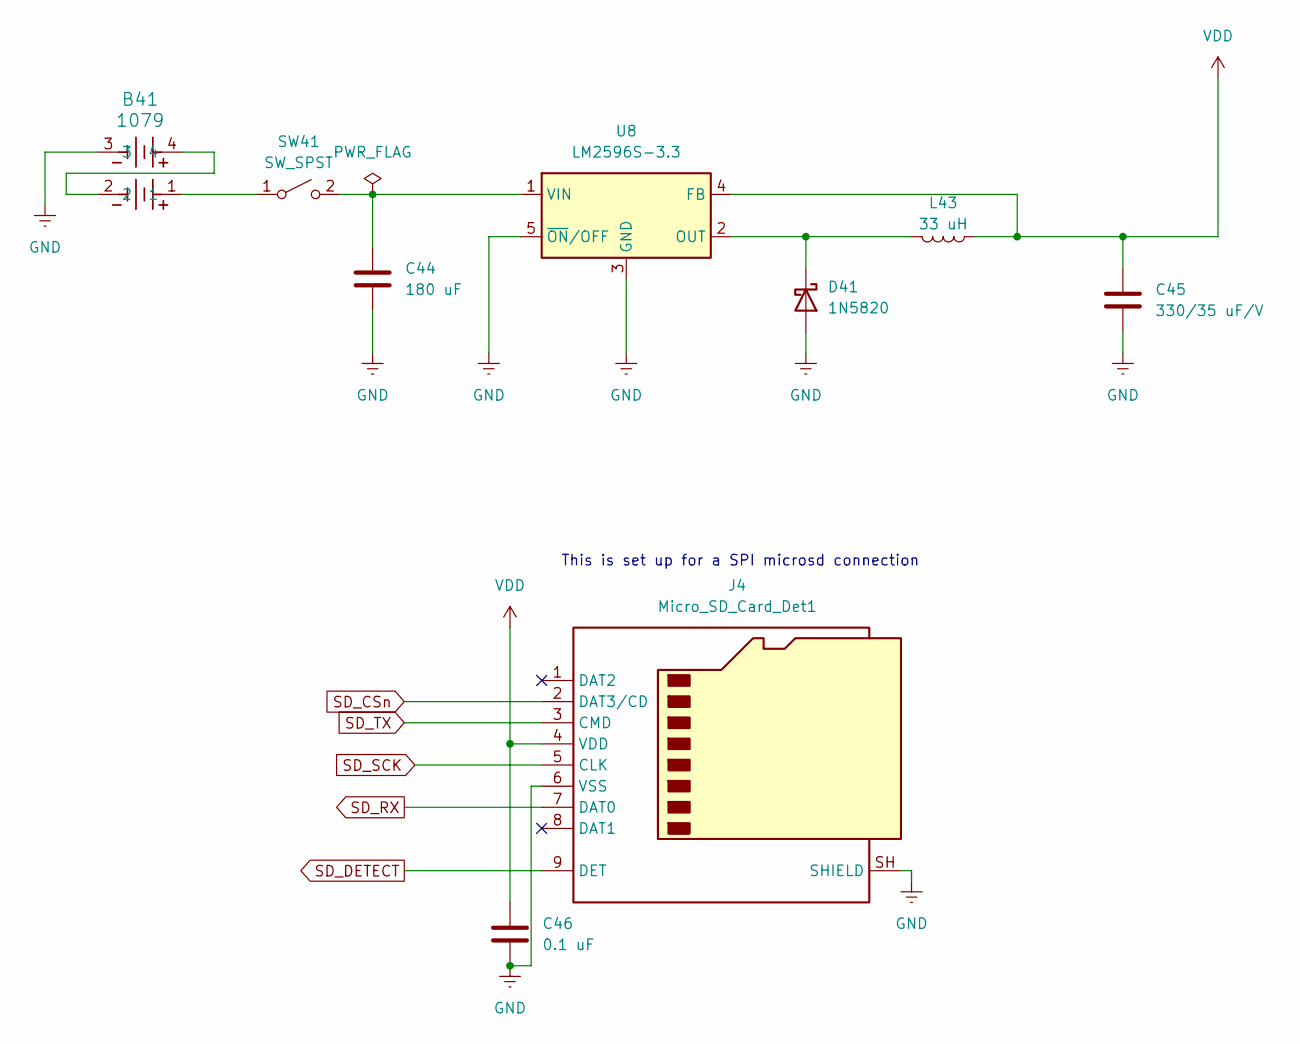
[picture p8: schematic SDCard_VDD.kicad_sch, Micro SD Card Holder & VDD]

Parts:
B41: 1079; 1079_KEY; Digikey Part Number 36-1079-ND
C44: 180 uF; CP_Elec_8x6.7; Digikey Part Number 399-A768KE187M1ELAE029CT-ND
C45: 330/35 uF/V; CP_Elec_10x10; Digikey Part Number 399-A768MS337M1VLAE022CT-ND
C46: 0.1 uF; C_0805_2012Metric; Digikey Part Number 478-KGM21NR71H104KTCT-ND
D41: 1N5820; D_A-405_P7.62mm_Horizontal; Digikey Part Number 4878-1N5820CT-ND
J4: Micro_SD_Card_Det1; microSD_HC_Molex_104031-0811; Digikey Part Number WM6357CT-ND
L43: 33 uH; L_Bourns-SRN8040_8x8.15mm; Digikey Part Number SRN8040TA-330MCT-ND
SW41: SW_SPST; SW_DIP_SPSTx01_Slide_9.78x4.72mm_W7.62mm_P2.54mm
U8: LM2596S-3.3; TO-263-5_TabPin3; Digikey Part Number 4518-LM2596S-3.3CT-ND

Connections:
GND: B41.3, C44.2, C45.2, C46.2, D41.2 (A), J4.6 (VSS), J4.SH (SHIELD), U8.3 (GND), U8.5 (~ON/OFF); also elsewhere on the board
unnamed: B41.2, B41.4
unnamed: D41.1 (K), L43.2, U8.2 (OUT)
unnamed: B41.1, SW41.1 (A)
unnamed: C44.1, SW41.2 (B), U8.1 (VIN)
SD_CSn: J4.2 (DAT3/CD); also elsewhere on the board
SD_DETECT: J4.9 (DET); also elsewhere on the board
SD_RX: J4.7 (DAT0); also elsewhere on the board
SD_SCK: J4.5 (CLK); also elsewhere on the board
SD_TX: J4.3 (CMD); also elsewhere on the board
VDD: C45.1, C46.1, J4.4 (VDD), L43.1, U8.4 (FB); also elsewhere on the board

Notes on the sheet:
This is set up for a SPI microsd connection

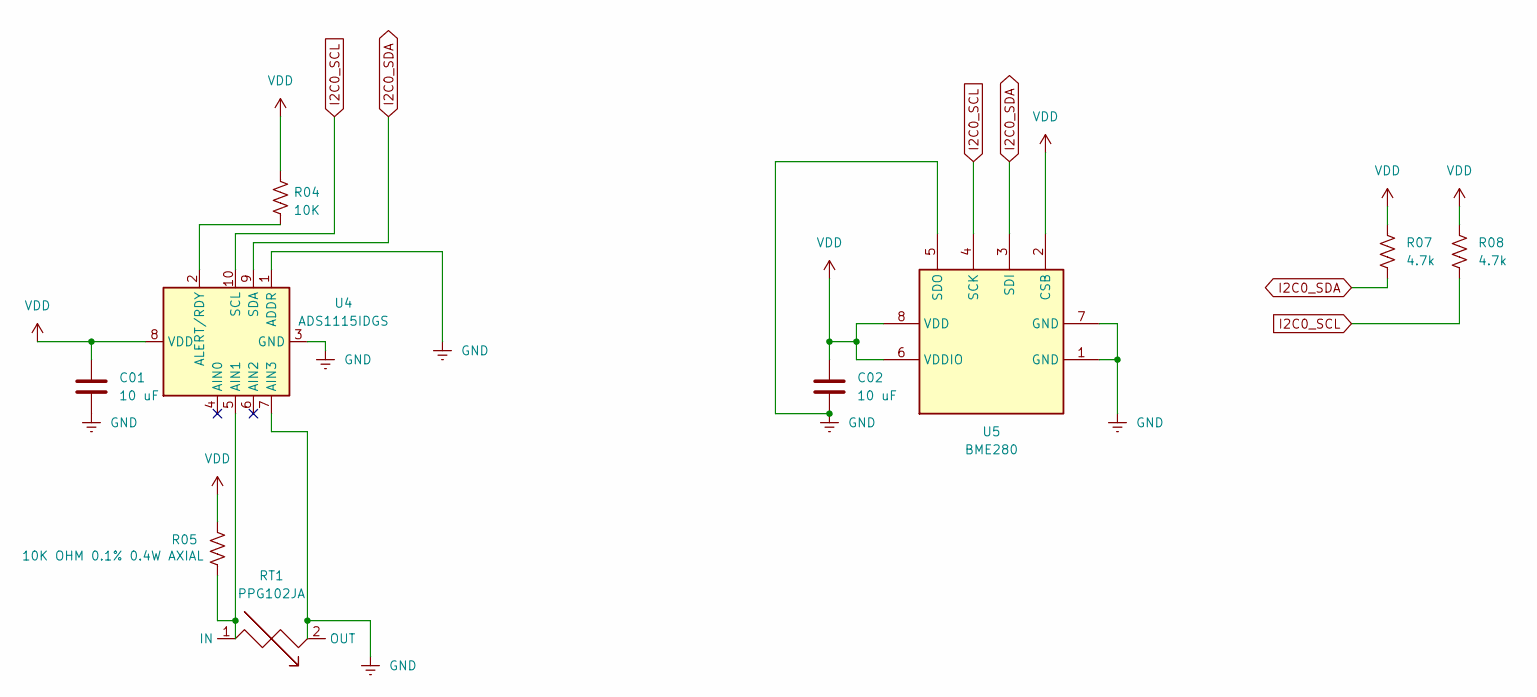
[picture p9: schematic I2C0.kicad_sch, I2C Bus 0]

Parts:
C01, C02: 10 uF; C_0603_1608Metric; Digikey Part Number 490-12538-1-ND
R04: 10K; R_0603_1608Metric; Digikey Part Number MCT0603-10.0K-CFCT-ND
R05: 10K OHM 0.1% 0.4W AXIAL; R_Axial_DIN0207_L6.3mm_D2.5mm_P7.62mm_Horizontal; Digikey Part Number BC4515CT-ND
R07, R08: 4.7k; R_0603_1608Metric; Digikey Part Number MCT0603-4.70K-CFCT-ND
RT1: PPG102JA; Digikey Part Number 5666-PPG102JA-ND
U4: ADS1115IDGS; TSSOP-10_3x3mm_P0.5mm; Digikey Part Number 296-38849-1-ND
U5: BME280; Bosch_LGA-8_2.5x2.5mm_P0.65mm_ClockwisePinNumbering; Digikey Part Number 828-1063-1-ND

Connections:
GND: C01.2, C02.2, RT1.2 (OUT), U4.1 (ADDR), U4.3 (GND), U4.7 (AIN3), U5.1 (GND), U5.5 (SDO), U5.7 (GND); also elsewhere on the board
I2C0_SCL: R08.2, U4.10 (SCL), U5.4 (SCK); also elsewhere on the board
I2C0_SDA: R07.2, U4.9 (SDA), U5.3 (SDI); also elsewhere on the board
unnamed: R05.2, RT1.1 (IN), U4.5 (AIN1)
unnamed: R04.2, U4.2 (ALERT/RDY)
VDD: C01.1, C02.1, R04.1, R05.1, R07.1, R08.1, U4.8 (VDD), U5.2 (CSB), U5.6 (VDDIO), U5.8 (VDD); also elsewhere on the board

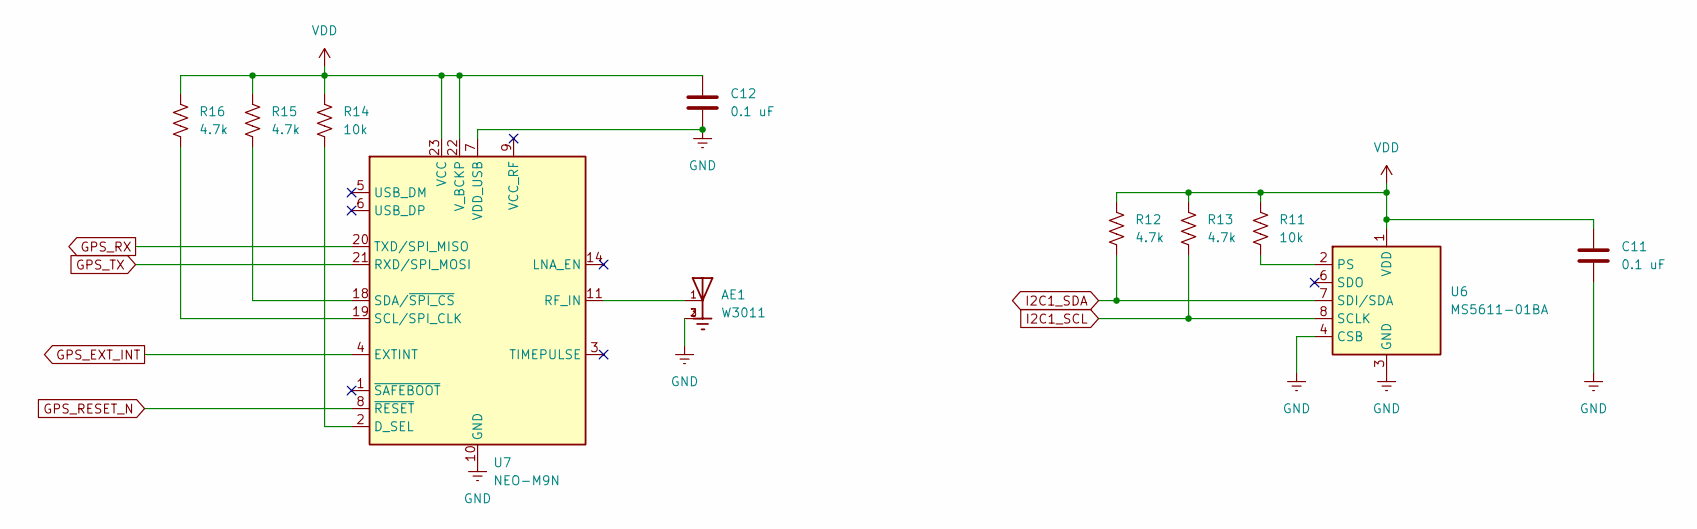
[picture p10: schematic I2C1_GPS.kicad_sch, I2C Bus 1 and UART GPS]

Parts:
AE1: W3011; XDCR_W3011; PARTREV N/A; Digikey Part Number 553-2582-1-ND
C11, C12: 0.1 uF; C_0805_2012Metric; Digikey Part Number 478-KGM21NR71H104KTCT-ND
R11, R14: 10k; R_0603_1608Metric; Digikey Part Number MCT0603-10.0K-CFCT-ND
R12, R13, R15, R16: 4.7k; R_0603_1608Metric; Digikey Part Number MCT0603-4.70K-CFCT-ND
U6: MS5611-01BA; LGA-8_3x5mm_P1.25mm; Digikey Part Number 223-1622-1-ND
U7: NEO-M9N; ublox_NEO; Digikey Part Number 672-NEO-M9N-00BCT-ND

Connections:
GND: AE1.2, AE1.3, C11.2, C12.2, U6.3 (GND), U6.4 (CSB), U6.5 (CSB), U7.7 (VDD_USB), U7.10 (GND), U7.12 (GND), U7.13 (GND), U7.24 (GND); also elsewhere on the board
GPS_EXT_INT: U7.4 (EXTINT); also elsewhere on the board
GPS_RESET_N: U7.8 (~RESET); also elsewhere on the board
GPS_RX: U7.20 (TXD/SPI_MISO); also elsewhere on the board
GPS_TX: U7.21 (RXD/SPI_MOSI); also elsewhere on the board
I2C1_SCL: R13.1, U6.8 (SCLK); also elsewhere on the board
I2C1_SDA: R12.1, U6.7 (SDI/SDA); also elsewhere on the board
unnamed: R11.1, U6.2 (PS)
unnamed: R14.2, U7.2 (D_SEL)
unnamed: AE1.1, U7.11 (RF_IN)
unnamed: R16.2, U7.19 (SCL/SPI_CLK)
unnamed: R15.2, U7.18 (SDA/~SPI_CS)
VDD: C11.1, C12.1, R11.2, R12.2, R13.2, R14.1, R15.1, R16.1, U6.1 (VDD), U7.22 (V_BCKP), U7.23 (VCC); also elsewhere on the board

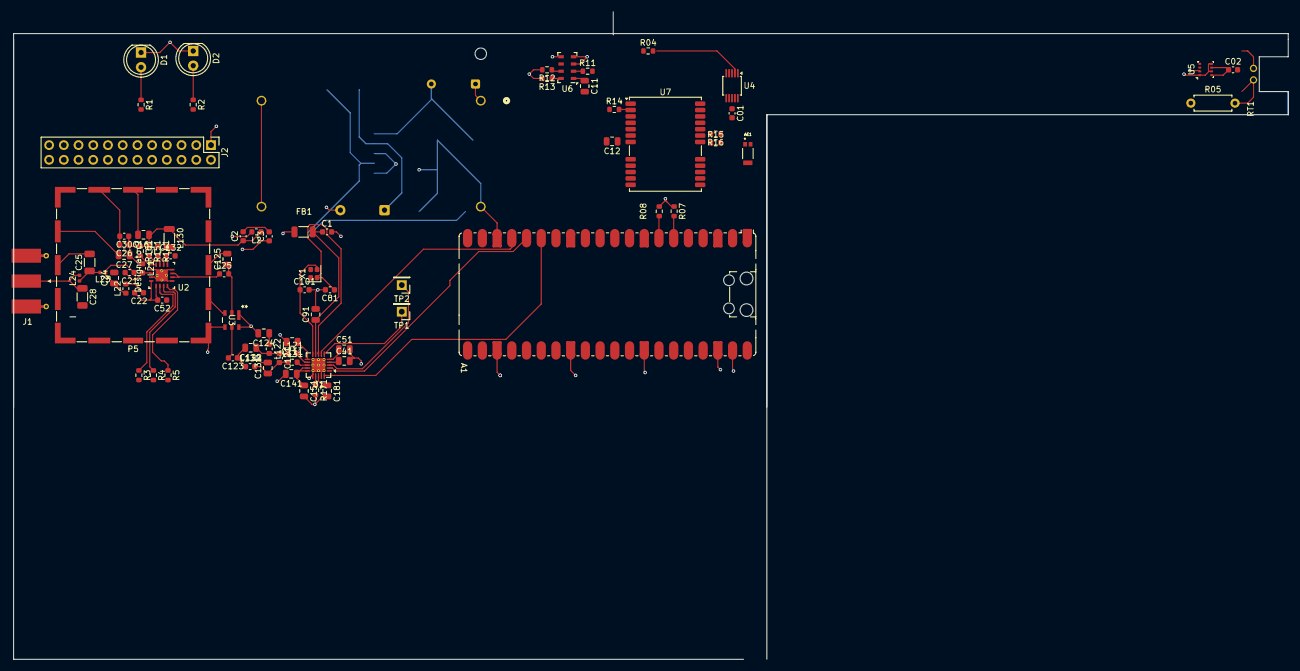
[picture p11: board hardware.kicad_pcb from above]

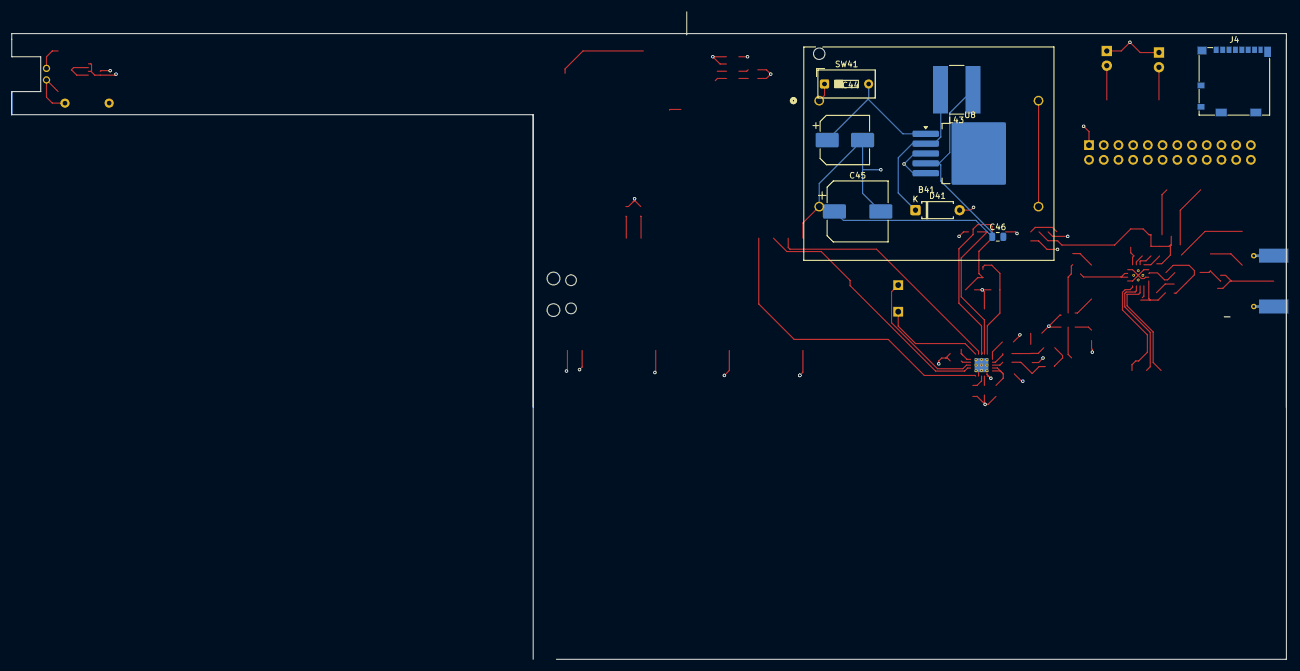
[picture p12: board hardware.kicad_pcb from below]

Board: 4 copper layers, 220.0 x 111.8 mm, 91 parts (9 on the bottom side), 68 nets.

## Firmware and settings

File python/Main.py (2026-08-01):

"""Met Pico main sample loop.

Initializes the full sensor suite, then runs a fixed-interval loop that
reads every sensor, assembles one packet.FIELD_NAMES record, appends it
to the SD card log, and builds a 38-byte iMet-1-RSB frame (GPS Data
Packet + PTU-enhanced Data Packet, see imet_packet.py) which is sent to
the RF Pico over the link UART for AFSK transmission. Also prints a
one-line summary to the console for live monitoring.

Sensors that fail to initialize or raise an error during read() report
NAN (or NO_DATA_U8 for the GPS satellite count) for their portion of
the record rather than halting the loop, per the "fail loudly in
development, not in flight" principle - a single bad sensor should not
take down the whole log.

Author: Nathaniel Peyer
Date: 06-14-2026
Last edited: 06-24-2026
"""

import time

from machine import I2C, Pin, UART

import config
import packet
import imet_packet
import link_uart
from bme280 import init_bme280
from ms5611 import init_ms5611
from bmi330 import init_bmi330
from rtd_ads1115 import init_ads1115
from gps_neo_m9n import init_gps
from sd_logger import init_sd_logger


def _safe_init(name, init_fn, *args):
    """Attempt to initialize a sensor, logging and continuing on failure.

    Args:
        name: Human-readable sensor name for log messages.
        init_fn: Callable that performs the initialization.
        *args: Positional arguments passed to init_fn.

    Returns:
        The result of init_fn(*args), or None if initialization raised
        OSError or ValueError.
    """
    try:
        return init_fn(*args)
    except (OSError, ValueError) as e:
        print("[WARN] {} init failed: {}".format(name, e))
        return None


def main():
    """Run the Met Pico sensor acquisition and logging loop."""
    # The 3.3V sensor rail is gated by the LM2596's EN pin - assert it
    # and give the regulator a moment to settle before touching any
    # I2C/UART peripheral, or every sensor init below will fail with
    # no ACK.
    regulator_en = Pin(config.REGULATOR_EN_PIN, Pin.OUT)
    regulator_en.value(1)
    time.sleep_ms(config.REGULATOR_ENABLE_DELAY_MS)

    # Hardware I2C on both buses now that the full sled has been
    # rewired to match the confirmed schematic pinout - the SoftI2C
    # workaround from initial bring-up was specific to the old, flipped
    # sled wiring and is no longer needed.
    i2c1 = I2C(config.I2C1,
               scl=Pin(config.I2C1_SCL_PIN),
               sda=Pin(config.I2C1_SDA_PIN),
               freq=config.I2C1_FREQ_HZ)

    i2c2 = I2C(config.I2C2,
               scl=Pin(config.I2C2_SCL_PIN),
               sda=Pin(config.I2C2_SDA_PIN),
               freq=config.I2C2_FREQ_HZ)

    # Status LEDs. LED0 (power/altitude) starts on - it is only turned
    # off once a GPS fix confirms the payload has climbed above
    # LED0_ALTITUDE_THRESHOLD_FT, and turned back on if it later
    # descends below that threshold. LED1 (GPS fix) starts off and
    # turns on the first time the GPS reports a valid fix.
    led0 = Pin(config.LED0_PIN, Pin.OUT)
    led1 = Pin(config.LED1_PIN, Pin.OUT)
    led0.value(1)
    led1.value(0)
    gps_has_fix = False

    try:
        gps_uart = UART(config.GPS_UART_ID,
                        baudrate=config.GPS_UART_BAUD_RATE,
                        tx=Pin(config.GPS_UART_TX_PIN),
                        rx=Pin(config.GPS_UART_RX_PIN))
    except (OSError, ValueError) as e:
        print("[WARN] GPS UART init failed: {}".format(e))
        gps_uart = None

    try:
        link_port = UART(config.LINK_UART_ID,
                         baudrate=config.LINK_UART_BAUD_RATE,
                         tx=Pin(config.LINK_UART_TX_PIN),
                         rx=Pin(config.LINK_UART_RX_PIN))
    except (OSError, ValueError) as e:
        print("[WARN] Link UART init failed: {}".format(e))
        link_port = None

    # ADS1115 and BME280 are on I2C bus 0 (I2C1 in config.py naming).
    # MS5611 and BMI330 are on I2C bus 1 (I2C2 in config.py naming).
    bme       = _safe_init("BME280",      init_bme280,  i2c1, config.BME280_I2C_ADDR)
    rtd       = _safe_init("RTD/ADS1115", init_ads1115, i2c1, config.ADS1115_I2C_ADDR)
    ms5611    = _safe_init("MS5611",      init_ms5611,  i2c2, config.MS5611_I2C_ADDR)
    bmi330    = _safe_init("BMI330",      init_bmi330,  i2c2, config.BMI330_I2C_ADDR)
    gps       = _safe_init("GPS/NEO-M9N", init_gps,     gps_uart)
    sd_logger = _safe_init("SD card",     init_sd_logger)

    next_sample_ms = time.ticks_ms()

    # Sequence number for the iMet PTU-enhanced packet's PKT field.
    # Wraps at 65536 (imet_packet.pack_ptu_enhanced_packet masks it too).
    imet_pkt_num = 0

    try:
        while True:
            now_ms = time.ticks_ms()
            if time.ticks_diff(now_ms, next_sample_ms) < 0:
                time.sleep_ms(1)
                continue
            next_sample_ms = time.ticks_add(next_sample_ms,
                                            config.SAMPLE_INTERVAL_MS)

            record = packet.new_blank_record()
            record["timestamp_ms"] = now_ms

            if bme is not None:
                try:
                    (record["bme280_temp_c"],
                     record["bme280_pressure_hpa"],
                     record["bme280_humidity_pct"]) = bme.read()
                except OSError as e:
                    print("[WARN] BME280 read failed: {}".format(e))

            if ms5611 is not None:
                try:
                    (record["ms5611_temp_c"],
                     record["ms5611_pressure_hpa"]) = ms5611.read()
                except OSError as e:
                    print("[WARN] MS5611 read failed: {}".format(e))

            if rtd is not None:
                try:
                    record["rtd_temp_c"] = rtd.read_temperature_c()
                except OSError as e:
                    print("[WARN] RTD/ADS1115 read failed: {}".format(e))

            if bmi330 is not None:
                try:
                    (record["bmi330_accel_x_mg"],
                     record["bmi330_accel_y_mg"],
                     record["bmi330_accel_z_mg"],
                     record["bmi330_gyro_x_mdps"],
                     record["bmi330_gyro_y_mdps"],
                     record["bmi330_gyro_z_mdps"]) = bmi330.read()
                except OSError as e:
                    print("[WARN] BMI330 read failed: {}".format(e))

            if gps is not None:
                try:
                    (record["gps_lat_deg"],
                     record["gps_lon_deg"],
                     record["gps_alt_m"],
                     record["gps_num_sats"],
                     record["gps_hour"],
                     record["gps_minute"],
                     record["gps_second"]) = gps.read()
                except OSError as e:
                    print("[WARN] GPS/NEO-M9N read failed: {}".format(e))

            # --- Status LED logic ---
            # gps_alt_m is MSL altitude straight from the GPS fix (no
            # ground-elevation offset applied yet - see config.py note on
            # LED0_ALTITUDE_THRESHOLD_FT for the AGL TODO). NaN until the
            # GPS has a valid fix, which read() guarantees via NO_DATA
            # sentinels - guard with the standard NaN self-inequality check
            # rather than comparing directly, since NaN comparisons are
            # always False and would otherwise silently leave LED0 on.
            gps_alt_m = record["gps_alt_m"]
            if gps_alt_m == gps_alt_m:
                if not gps_has_fix:
                    gps_has_fix = True
                    led1.value(1)
                altitude_ft = gps_alt_m * 3.28084
                if altitude_ft >= config.LED0_ALTITUDE_THRESHOLD_FT:
                    led0.value(0)
                else:
                    led0.value(1)

            record_bytes = packet.pack_record(record)

            if sd_logger is not None:
                try:
                    sd_logger.write_record(record_bytes)
                except (OSError, MemoryError) as e:
                    print("[WARN] SD card log append failed: {}".format(e))

            # --- iMet-1-RSB downlink frame ---
            # Sensor -> iMet field mapping (see imet_packet.py for field
            # definitions; this mapping is just keyword arguments below,
            # so it's a one-line change if you want a different sensor in
            # a given slot):
            #   GPS lat/lon/alt/num_sats/hour/min/sec -> straight from the
            #                               GPS record fields
            #   P    (pressure)          -> ms5611_pressure_hpa (TODO:
            #                               confirm - currently NAN since
            #                               MS5611 read may still fail on
            #                               first hardware bring-up)
            #   T    (primary temp)      -> bme280_temp_c
            #   U    (humidity)          -> bme280_humidity_pct
            #   Vbat (battery voltage)   -> not yet measured; NAN = no data
            #   Tint (internal temp)     -> bme280_temp_c (TODO: confirm -
            #                               currently duplicates T)
            #   Tpr  (probe temp)        -> rtd_temp_c
            #   Tu   (aux temp)          -> not yet mapped; NAN = no data
            imet_frame = imet_packet.pack_frame(
                {
                    "lat_deg":  record["gps_lat_deg"],
                    "lon_deg":  record["gps_lon_deg"],
                    "alt_m":    record["gps_alt_m"],
                    "num_sats": record["gps_num_sats"],
                    "hour":     record["gps_hour"],
                    "minute":   record["gps_minute"],
                    "second":   record["gps_second"],
                },
                {
                    "pkt_num":      imet_pkt_num,
                    "pressure_hpa": record["ms5611_pressure_hpa"],
                    "temp_c":       record["bme280_temp_c"],
                    "humidity_pct": record["bme280_humidity_pct"],
                    "vbat_v":       packet.NAN,
                    "temp_int_c":   record["bme280_temp_c"],
                    "temp_probe_c": record["rtd_temp_c"],
                    "temp_u_c":     packet.NAN,
                })
            imet_pkt_num = (imet_pkt_num + 1) & 0xFFFF

            if link_port is not None:
                try:
                    link_uart.send_record(link_port, imet_frame)
                except OSError as e:
                    print("[WARN] Link UART send failed: {}".format(e))

            print("t={:>8d}ms  T={:6.2f}C  P={:7.2f}hPa  RH={:5.1f}%  "
                  "RTD={:6.2f}C  MS_T={:6.2f}C  MS_P={:7.2f}hPa  "
                  "AX={:7.1f}mg  AY={:7.1f}mg  AZ={:7.1f}mg  "
                  "GX={:8.1f}mdps  GY={:8.1f}mdps  GZ={:8.1f}mdps  "
                  "LAT={:9.5f}  LON={:10.5f}  ALT={:7.1f}m  "
                  "SATS={:3d}".format(
                      record["timestamp_ms"], record["bme280_temp_c"],
                      record["bme280_pressure_hpa"],
                      record["bme280_humidity_pct"], record["rtd_temp_c"],
                      record["ms5611_temp_c"], record["ms5611_pressure_hpa"],
                      record["bmi330_accel_x_mg"], record["bmi330_accel_y_mg"],
                      record["bmi330_accel_z_mg"], record["bmi330_gyro_x_mdps"],
                      record["bmi330_gyro_y_mdps"], record["bmi330_gyro_z_mdps"],
                      record["gps_lat_deg"], record["gps_lon_deg"],
                      record["gps_alt_m"], record["gps_num_sats"]))

    except KeyboardInterrupt:
        pass

    finally:
        print("[INFO] Shutting down...")
        if sd_logger is not None:
            try:
                sd_logger.close()
                print("[INFO] SD card closed cleanly.")
            except Exception as e:
                print("[WARN] SD close failed: {}".format(e))


if __name__ == "__main__":
    main()

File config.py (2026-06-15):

"""Hardware configuration constants for the Met Pico sensor suite.

Centralizes pin assignments, bus addresses, ADC channel mappings, and
calibration constants so that hardware changes only require edits in
this file. Values marked TODO are placeholders pending hardware
confirmation and must be updated before flight.

Author: Nathaniel Peyer
Date: 06-14-2026
"""

# I2C bus 1: ADS1115 (RTD interface) and BME280.
I2C1 = 0
I2C1_SDA_PIN = 0
I2C1_SCL_PIN = 1
I2C1_FREQ_HZ = 400000

# I2C bus 2: MS5611 and BMI330.
# TODO: confirm BMI330 is on I2C (vs SPI) once hardware is finalized -
# this assumes both remaining I2C sensors share the second bus.
I2C2 = 1
I2C2_SDA_PIN = 2
I2C2_SCL_PIN = 3
I2C2_FREQ_HZ = 400000

# BME280 (temperature / pressure / humidity).
BME280_I2C_ADDR = 0x76

# MS5611 (high-resolution pressure / temperature).
# TODO: confirm address (0x77 if CSB tied high, 0x76 if tied low).
MS5611_I2C_ADDR = 0x77

# BMI330 (6-axis IMU).
# TODO: confirm address and bus once hardware is finalized.
BMI330_I2C_ADDR = 0x68

# ADS1115 (4-wire PT1000 RTD interface).
ADS1115_I2C_ADDR = 0x48

# ADS1115 MUX[2:0] codes (config register bits 14:12) select which
# differential pair is measured. The ADS1115 only supports four
# differential combinations:
#   0b000 -> AIN0 - AIN1
#   0b001 -> AIN0 - AIN3
#   0b010 -> AIN1 - AIN3
#   0b011 -> AIN2 - AIN3
# TODO: confirm which pair carries the RTD sense voltage and which
# carries the reference resistor once the RTD interface board wiring
# is finalized.
RTD_MUX = 0b000
REF_MUX = 0b011

# ADS1115 PGA[2:0] code (config register bits 11:9) sets the full-scale
# input range:
#   0 -> +/-6.144V   1 -> +/-4.096V   2 -> +/-2.048V
#   3 -> +/-1.024V   4 -> +/-0.512V   5 -> +/-0.256V
# TODO: confirm once excitation current and the expected voltage range
# across the RTD and reference resistor are known.
ADS1115_GAIN = 1

RTD_REF_RESISTANCE_OHMS = 10000.0

# Callendar-Van Dusen coefficients for PT1000 (IEC 60751), valid for
# T >= 0 deg C.
RTD_R0_OHMS = 1000.0
RTD_CVD_A = 3.9083e-3
RTD_CVD_B = -5.775e-7

# NEO-M9N GPS (UART, NMEA 0183).
GPS_UART_ID = 1
GPS_UART_TX_PIN = 4
GPS_UART_RX_PIN = 5
GPS_UART_BAUD_RATE = 9600

# UART link to the RF Pico - one packet.pack_record() payload, framed
# by link_uart.send_record(), is sent each sample cycle.
# TODO: confirm pins and baud rate once the inter-Pico wiring is set.
LINK_UART_ID = 0
LINK_UART_TX_PIN = 12
LINK_UART_RX_PIN = 13
LINK_UART_BAUD_RATE = 115200

# SD card (SPI).
SD_SPI_ID = 0
SD_SCK_PIN = 18
SD_MOSI_PIN = 19
SD_MISO_PIN = 16
SD_CS_PIN = 17
SD_MOUNT_POINT = "/sd"
SD_LOG_FILENAME = "/sd/metlog.bin"

# LM2596 switching regulator that supplies the 3.3V sensor rail. This
# GPIO must be driven high before any I2C/UART sensor transaction will
# succeed - main() asserts it first thing, then waits
# REGULATOR_ENABLE_DELAY_MS for the rail to settle.
# TODO: confirm pin number once wiring is finalized.
REGULATOR_EN_PIN = 14
REGULATOR_ENABLE_DELAY_MS = 50

# Sampling and logging cadence.
SAMPLE_INTERVAL_MS = 1000
SD_FLUSH_INTERVAL_SAMPLES = 5

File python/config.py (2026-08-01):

"""Hardware configuration constants for the Met Pico sensor suite.

Centralizes pin assignments, bus addresses, ADC channel mappings, and
calibration constants so that hardware changes only require edits in
this file. Values marked TODO are placeholders pending hardware
confirmation and must be updated before flight.

Author: Nathaniel Peyer
Date: 06-16-2026
"""

# I2C bus 0: ADS1115 (RTD interface) and BME280.
# Pins per the PiCowbell Adalogger schematic / RP2350 primary I2C0
# pinout (confirmed 2026-06-20). Bus is hardware I2C, not SoftI2C -
# the SoftI2C/GP10/GP11 workaround from earlier bring-up was specific
# to the flipped sled wiring and is no longer needed at these pins.
I2C1 = 0
I2C1_SDA_PIN = 4
I2C1_SCL_PIN = 5
I2C1_FREQ_HZ = 400000
 
# I2C bus 1: MS5611 and BMI330.
# TODO: confirm BMI330 is on I2C (vs SPI) once hardware is finalized -
# this assumes both remaining I2C sensors share the second bus.
# Pins per the RP2350 primary I2C1 pinout (confirmed 2026-06-20).
I2C2 = 1
I2C2_SDA_PIN = 26
I2C2_SCL_PIN = 27
I2C2_FREQ_HZ = 400000
 
# BME280 (temperature / pressure / humidity).
BME280_I2C_ADDR = 0x77
 
# MS5611 (high-resolution pressure / temperature).
# TODO: confirm address (0x77 if CSB tied high, 0x76 if tied low).
MS5611_I2C_ADDR = 0x77
 
# BMI330 (6-axis IMU).
# TODO: confirm address and bus once hardware is finalized.
BMI330_I2C_ADDR = 0x69
 
# ADS1115 (4-wire PT1000 RTD interface).
ADS1115_I2C_ADDR = 0x48
 
# ADS1115 MUX[2:0] codes (config register bits 14:12) select which
# differential pair is measured. The ADS1115 only supports four
# differential combinations:
#   0b000 -> AIN0 - AIN1
#   0b001 -> AIN0 - AIN3
#   0b010 -> AIN1 - AIN3
#   0b011 -> AIN2 - AIN3
# TODO: confirm which pair carries the RTD sense voltage and which
# carries the reference resistor once the RTD interface board wiring
# is finalized.
# AIN1 - AIN3 differential: high-side tap (between ref resistor and RTD)
# to low-side tap (between RTD and GND).
RTD_MUX = 0b010
 
# Excitation voltage in volts (3.3V regulated buck converter output).
# Used in voltage-divider resistance calculation since only one
# differential pair is available (no separate ref resistor tap).
RTD_EXCITATION_V = 3.3
 
# ADS1115 full-scale voltage for GAIN=1 (+-4.096V). One LSB = 0.125mV.
ADS1115_FSV = 4.096
 
# ADS1115 PGA[2:0] code (config register bits 11:9) sets the full-scale
# input range:
#   0 -> +/-6.144V   1 -> +/-4.096V   2 -> +/-2.048V
#   3 -> +/-1.024V   4 -> +/-0.512V   5 -> +/-0.256V
# TODO: confirm once excitation current and the expected voltage range
# across the RTD and reference resistor are known.
ADS1115_GAIN = 1
 
RTD_REF_RESISTANCE_OHMS = 10000.0
 
# Callendar-Van Dusen coefficients for PT1000 (IEC 60751).
RTD_R0_OHMS = 1000.0
RTD_CVD_A = 3.9083e-3
RTD_CVD_B = -5.775e-7
# Cubic term, only used for T < 0 deg C (see rtd_ads1115.py).
RTD_CVD_C = -4.183e-12
 
# Newton-Raphson iterations for the sub-zero CVD inversion. The
# quadratic (T >= 0) estimate used as the starting guess is already
# close, so this converges to well under 0.001 deg C within 2-3
# iterations; 5 leaves comfortable margin.
RTD_SUBZERO_ITERATIONS = 5
 
# NEO-M9N GPS (UART, NMEA 0183).
# Pins per the RP2350 primary UART1 pinout (confirmed 2026-06-20).
GPS_UART_ID = 1
GPS_UART_TX_PIN = 8
GPS_UART_RX_PIN = 9
GPS_UART_BAUD_RATE = 38400
 
# UART link to the FC Pico - one 38-byte iMet-1-RSB frame (see
# imet_packet.py), framed by link_uart.send_record(), is sent each
# sample cycle for the FC Pico to AFSK-modulate.
# TODO: confirm baud rate once the inter-Pico wiring is set.
# Pins per the RP2350 primary UART0 pinout (confirmed 2026-06-20).
LINK_UART_ID = 0
LINK_UART_TX_PIN = 0
LINK_UART_RX_PIN = 1
LINK_UART_BAUD_RATE = 115200
 
# SD card (SPI).
SD_SPI_ID = 0
SD_SCK_PIN = 18
SD_MOSI_PIN = 19
SD_MISO_PIN = 16
SD_CS_PIN = 17
SD_MOUNT_POINT = "/sd"
SD_LOG_FILENAME = "/sd/metlog.bin"
 
# LM2596 switching regulator that supplies the 3.3V sensor rail. This
# GPIO must be driven high before any I2C/UART sensor transaction will
# succeed - main() asserts it first thing, then waits
# REGULATOR_ENABLE_DELAY_MS for the rail to settle.
# TODO: confirm pin number once wiring is finalized.
REGULATOR_EN_PIN = 14
REGULATOR_ENABLE_DELAY_MS = 50
 
# Status LEDs (confirmed 2026-06-20).
# LED0: power/altitude status. On below LED0_ALTITUDE_THRESHOLD_FT,
# off above it (see main.py altitude-gated LED logic, RED).
# LED1: GPS fix status. Off until the GPS reports a valid fix, then on (Blue).
# TODO: LED0_ALTITUDE_THRESHOLD_FT is currently MSL (sea level), not
# true AGL - revisit once launching from a site with non-trivial
# ground elevation (decided 2026-06-20 to defer this).
LED0_PIN = 6
LED1_PIN = 7
LED0_ALTITUDE_THRESHOLD_FT = 5000.0
 
# Sampling and logging cadence.
SAMPLE_INTERVAL_MS = 1000
SD_FLUSH_INTERVAL_SAMPLES = 5

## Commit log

2026-06-15 restructured repo and added more sensor drivers - NWP
2026-06-15 Added more drivers and fixed all present VSCode errors. - NWP
    [Main.py, bmi330.py, gps_neo_m9n.py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]
2026-06-19 Working on fixing the RTD and other sensor readings. - NWP
    [Main.py, rtd_ads1115.py]
2026-06-20 Fixed pin mapping for the new hardware. - NWP
    [Main.py, config.py]
2026-08-01 Adding schematic for backup purposes
    [5025700893.stl, B39162B3522U410_TDK.stl, DGS0010A.stl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]
2026-08-01 Updated schematic with better design practices.
    [hardware.kicad_sch]
2026-08-16 Added sub pages for different systems.
    [I2C0.kicad_sch, I2C1_GPS.kicad_sch, SDCard_VDD.kicad_sch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]
2026-08-17 More work on the scehmatic for I2C0 and I2C1 + UART GPS.
    [I2C0.kicad_sch, I2C1_GPS.kicad_sch, hardware.kicad_sch]
2026-08-17 Finished rough draft of the schematic.
    [I2C0.kicad_sch, SDCard_VDD.kicad_sch, hardware.kicad_sch]
2026-08-18 Fixed EEC errors.
    [I2C0.kicad_sch, I2C1_GPS.kicad_sch, SDCard_VDD.kicad_sch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]
2026-08-19 Added footprints for the resitors.
    [I2C0.kicad_sch, I2C1_GPS.kicad_sch, hardware.kicad_sch]
2026-08-19 Added capacitor footprints.
    [I2C0.kicad_sch, I2C1_GPS.kicad_sch, SDCard_VDD.kicad_sch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]
2026-08-20 Worked on footprints and hardware definations.
    [I2C0.kicad_sch, I2C1_GPS.kicad_sch, SDCard_VDD.kicad_sch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]
2026-08-22 Fixed I2C1 global labels.
    [I2C1_GPS.kicad_sch, hardware.kicad_pcb, hardware.kicad_sch]
2026-09-14 Worked on PCB routing and component placement.
    [CC1101-CC1190EM_915MHz_PARTLIST_1_2_0.xls, I2C0.kicad_sch, I2C1_GPS.kicad_sch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]
2026-09-15 Fixed an issue with a spreadsheet saving.
    [CC1101-CC1190EM_915MHz_PARTLIST_1_2_0.ods]
2026-09-15 Worked more on the PCB layout.
    [hardware.kicad_pcb]
2026-11-10 This rev of the board was sent to OSH Park for manufacturing (09 Novemeber 2026).

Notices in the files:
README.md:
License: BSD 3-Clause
